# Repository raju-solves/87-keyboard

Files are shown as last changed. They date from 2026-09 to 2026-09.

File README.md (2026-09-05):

This project is a custom designed 87% ortholinear mechanical keyboard built as a PCB design and firmware learning experience It includes the PCB layout, CAD files, and firmware and lot of hardwork

I built this project to deepen my understanding of PCB design, keyboard matrix layouts, and CAD designing I wanted hands-on experience creating a mechanical keyboard from the scratch while also designing something practical and customized to my preference

602219003-d21ecfe0-0ab5-4783-b61b-950d579dc5c7
602219525-ffc2832b-7c2d-4a44-8d97-b2ba8af0c2ea
602219453-233b2a96-449a-4178-899f-5ae475d09add
602219381-5aa06178-03f3-4e05-a3e9-fc6733033b2a
602219333-37990960-18a9-4696-a77a-dc775576d171
602219100-f991f15e-3d26-4ee0-b814-e6c4a3add098
602219280-15e8cf9d-5e58-42b5-828d-d92529df9ab9
602219214-5e932b3e-5503-4928-bb83-d3fdaf1ea26e
602218932-bbe01e49-c888-48cc-bc79-f7ac42afa11e

| Name | Description | Quantity | Price (USD) | Link | Vendor |
|---|---|---|---|---|---|
| Gateron Mechanical Switches (G Pro 3.0 Yellow Pre-lubed) | Linear pre-lubed keyboard switches (~50g actuation, smooth) | 90 | 17.06 | https://www.thecosmicbyte.com/product/gateron-mechanical-switches-compatible-with-cosmic-byte-hot-swappable-keyboards-qty-1pc/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 | Cosmic Byte |
| Keycaps | Mechanical keyboard keycap set (standard layout) | 90 | 16.19 | https://amzn.in/d/05XbxYkm | Amazon |
| Diodes | General purpose diodes for keyboard matrix | 100 | 2.65 | https://amzn.in/d/0eVDrr6B | Amazon |
| PCB | Custom keyboard printed circuit board | 1 | 42.97 | N/A | JLCPCB |
| RP2040 | Microcontroller board (dual-core ARM Cortex-M0+) | 1 | 8.09 | https://amzn.in/d/00qoAonb | Amazon |
| Screws | Small M2/M2.5 screws for keyboard assembly | 1 pack | 1.53 | https://amzn.in/d/04wa89yN | Amazon |
| Stabilizers | PCB/plate mount stabilizers for larger keys | 1 set | 2.56 | https://www.aliexpress.us/item/3256806342416791.html | AliExpress |
| Soldering Iron | Basic soldering iron for assembling PCB components | 1 | 5.96 | https://amzn.in/d/032QO002 | Amazon |

**Total Cost: 99.01 USD**

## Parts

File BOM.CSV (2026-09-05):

# BOM
 | Name | Description | Quantity | Price (USD) | Link | Vendor
 | --- | --- | ---: | ---: | --- | ---
 | Gateron Mechanical Switches (G Pro 3.0 Yellow Pre-lubed) | Linear pre-lubed keyboard switches (~50g actuation, smooth) | 90 | $17.06 | [Product Link](https://www.thecosmicbyte.com/product/gateron-mechanical-switches-compatible-with-cosmic-byte-hot-swappable-keyboards-qty-1pc/ | Cosmic Byte
 | Keycaps | Mechanical keyboard keycap set (standard layout) | 90 | $16.19 | [Product Link](https://amzn.in/d/05XbxYkm) | Amazon
 | Diodes | General purpose diodes for keyboard matrix | 100 | $2.65 | [Product Link](https://amzn.in/d/0eVDrr6B) | Amazon
 | PCB | Custom keyboard printed circuit board | 1 | $42.97 | N/A | JLCPCB
 | RP2040 | Microcontroller board (dual-core ARM Cortex-M0+) | 1 | $8.09 | [Product Link](https://amzn.in/d/00qoAonb) | Amazon
 | Screws | Small M2/M2.5 screws for keyboard assembly | 1 pack | $1.53 | [Product Link](https://amzn.in/d/04wa89yN) | Amazon
 | Stabilizers | PCB/plate mount stabilizers for larger keys | 1 set | $2.56 | [Product Link](https://www.aliexpress.us/item/3256806342416791.html) | AliExpress
 | Soldering Iron | Basic soldering iron for assembling PCB components | 1 | $5.96 | [Product Link](https://amzn.in/d/032QO002) | Amazon
 | **Total** |  |  | **$97.01**

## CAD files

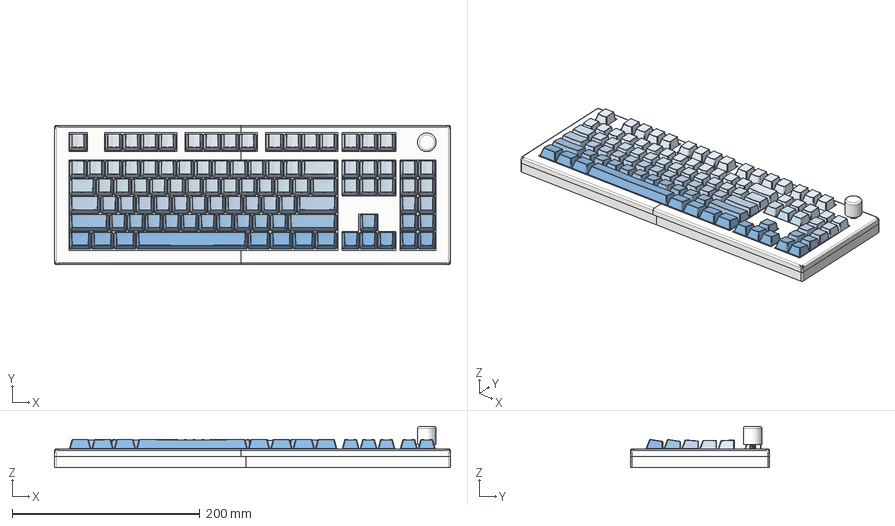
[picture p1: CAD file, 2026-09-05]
CAD/Assembly.step
421.8 x 148.4 x 43.8 mm

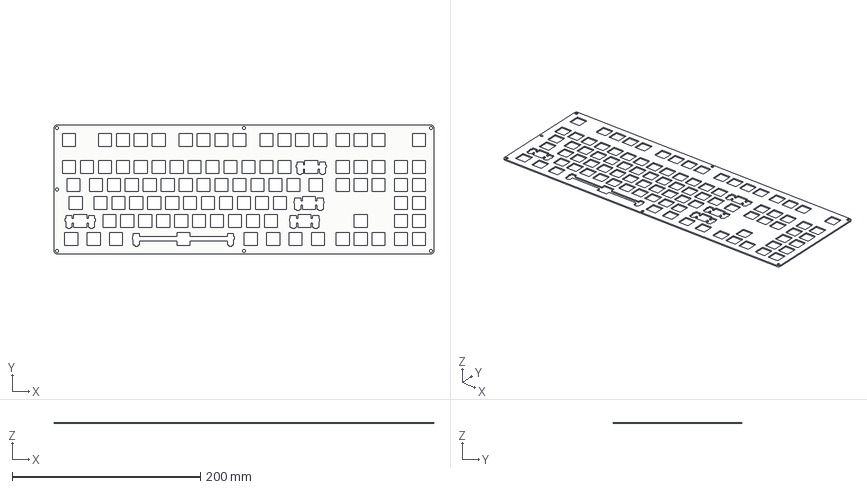
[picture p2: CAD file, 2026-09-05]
CAD/plate.step
403.3 x 136.6 x 1.50 mm

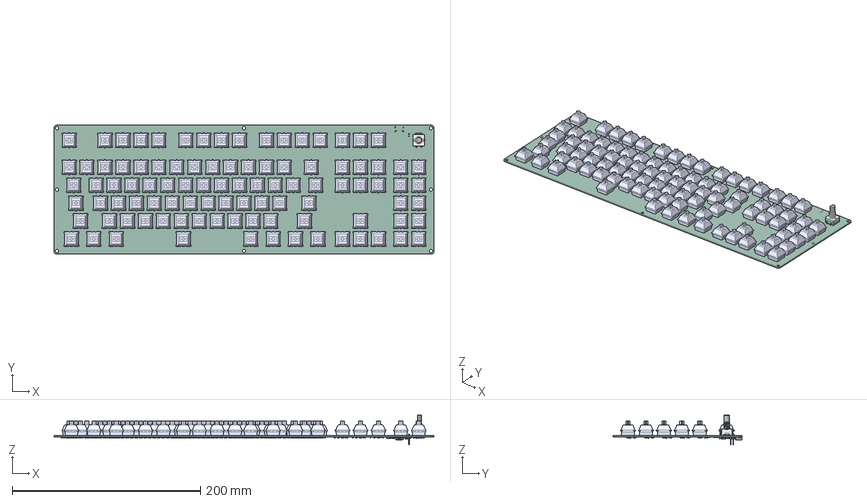
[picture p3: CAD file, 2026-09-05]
CAD/PCB.step
403.8 x 137.5 x 31.6 mm
Cherry_MX_Switch x 97
EC11_Vertical
D_SOD-323 x 98
PinHeader_1x02_P2.54mm_Vertical
C_0402_1005Metric x 15
R_0402_1005Metric x 6
R_0603_1608Metric x 2
C_1206_3216Metric x 2
Crystal_SMD_3225-4Pin_3.2x2.5mm
ConPins
PcbPins
Mold
Frame
QFN-56-1EP_7x7mm_P0.4mm_EP3.2x3.2mm
SOT-223
SOIC-8_3.9x4.9mm_P1.27mm
SOIC-8_5.3x5.3mm_P1.27mm
MacroBoard_PCB

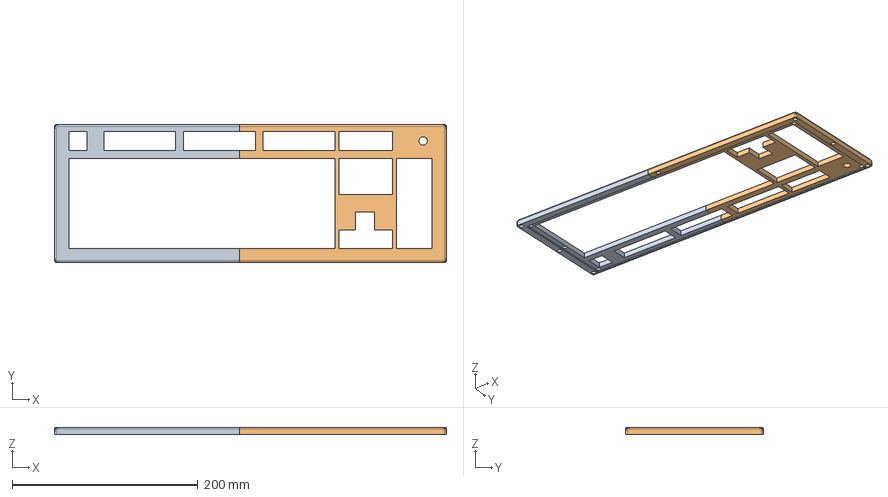
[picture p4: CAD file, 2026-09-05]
CAD/CaseTop.step
421.8 x 148.4 x 8.00 mm

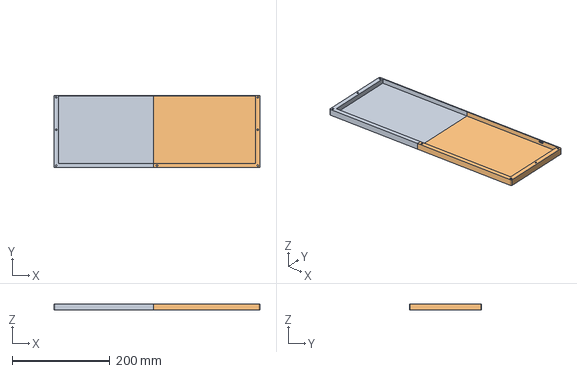
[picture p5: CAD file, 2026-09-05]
CAD/CaseBottom.step
421.8 x 148.4 x 12.0 mm

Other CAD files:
SOURCE FILE/MYKEEBO.FCStd

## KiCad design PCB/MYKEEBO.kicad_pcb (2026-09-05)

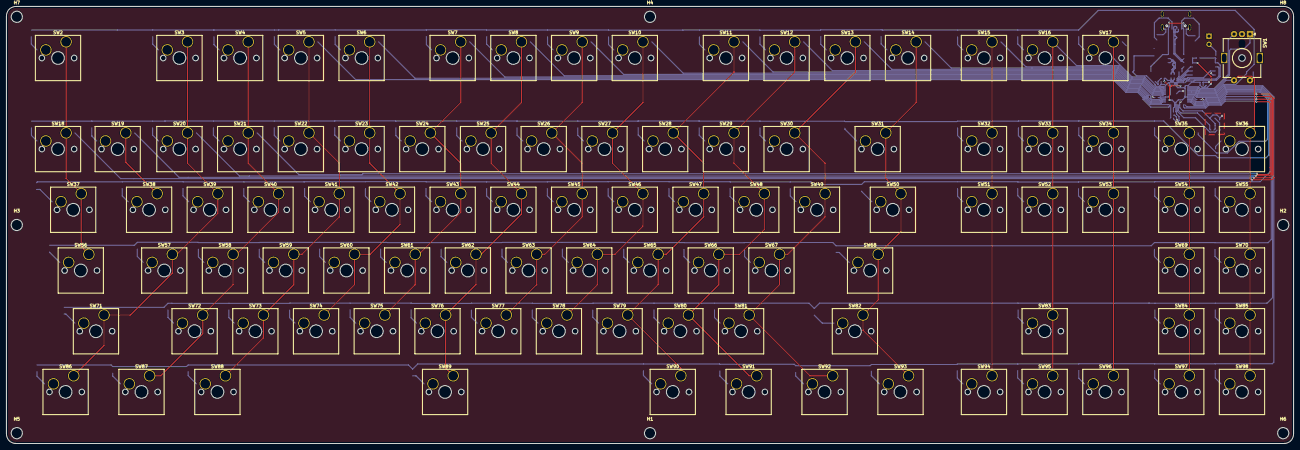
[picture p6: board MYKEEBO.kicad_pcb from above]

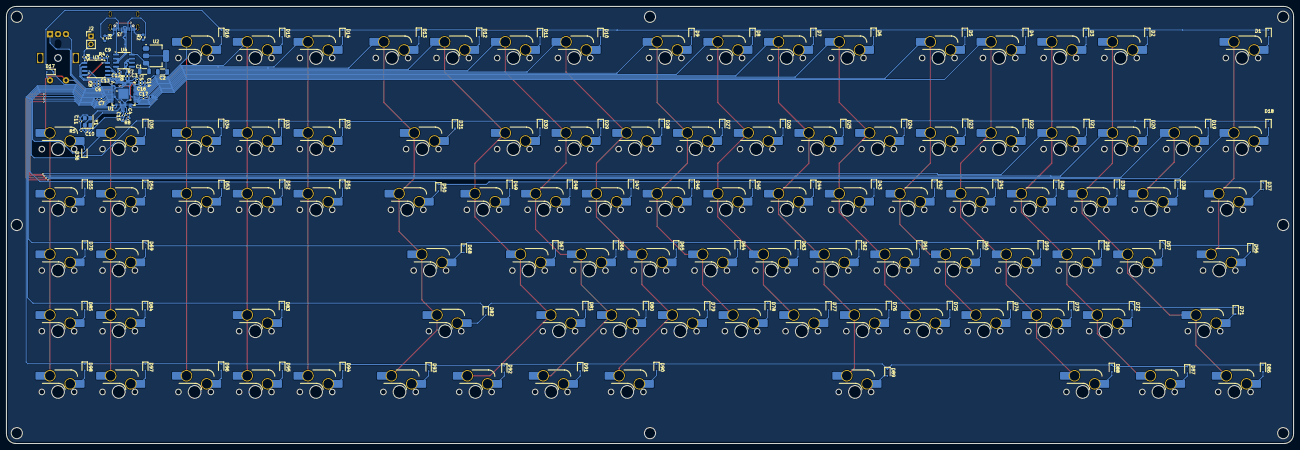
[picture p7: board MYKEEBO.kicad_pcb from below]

Board: 2 copper layers, 403.8 x 137.1 mm, 236 parts (130 on the bottom side), 148 nets.

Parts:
C1, C2: C10u; C_1206_3216Metric
C3, C5: C1u; C_0402_1005Metric
C4, C6, C7, C8, C9, C12, C13, C14, C15, C16, C17: C100n; C_0402_1005Metric
C10, C11: C15p; C_0402_1005Metric
D1: Esc; D_SOD-323
D2: F1; D_SOD-323
D3: F2; D_SOD-323
D4: F3; D_SOD-323
D5: F4; D_SOD-323
D6: F5; D_SOD-323
D7: F6; D_SOD-323
D8: F7; D_SOD-323
D9: F8; D_SOD-323
D10: F9; D_SOD-323
D11: F10; D_SOD-323
D12: F11; D_SOD-323
D13: F12; D_SOD-323
D14: PrtScrn; D_SOD-323
D15: Screen Lock; D_SOD-323
D16: Pause; D_SOD-323
D17: D; D_SOD-323
D18: KEY`; D_SOD-323
D19: KEY1; D_SOD-323
D20: KEY2; D_SOD-323
D21: KEY3; D_SOD-323
D22: KEY4; D_SOD-323
D23: KEY5; D_SOD-323
D24: KEY6; D_SOD-323
D25: KEY7; D_SOD-323
D26: KEY8; D_SOD-323
D27: KEY9; D_SOD-323
D28: KEY0; D_SOD-323
D29: KEY-; D_SOD-323
D30: KEY=; D_SOD-323
D31: BKSP; D_SOD-323
D32: Ins; D_SOD-323
D33: Home; D_SOD-323
D34: PgUP; D_SOD-323
D35: M1; D_SOD-323
D36: M2; D_SOD-323
D37: TAB; D_SOD-323
D38: KEYQ; D_SOD-323
D39: KEYW; D_SOD-323
D40: KEYE; D_SOD-323
D41: KEYR; D_SOD-323
D42: KEYT; D_SOD-323
D43: KEYY; D_SOD-323
D44: KEYU; D_SOD-323
D45: KEYI; D_SOD-323
D46: KEYO; D_SOD-323
D47: KEYP; D_SOD-323
D48: KEY[; D_SOD-323
D49: KEY]; D_SOD-323
D50: KEY\; D_SOD-323
D51: Del; D_SOD-323
D52: End; D_SOD-323
D53: PgDN; D_SOD-323
D54: M3; D_SOD-323
D55: M4; D_SOD-323
D56: CAPS; D_SOD-323
D57: KEYA; D_SOD-323
D58: KEYS; D_SOD-323
D59: KEYD; D_SOD-323
D60: KEYF; D_SOD-323
D61: KEYG; D_SOD-323
D62: KEYH; D_SOD-323
D63: KEYJ; D_SOD-323
D64: KEYK; D_SOD-323
D65: KEYL; D_SOD-323
D66: KEY;; D_SOD-323
D67: KEY"; D_SOD-323
D68: ENTER; D_SOD-323
D69: M5; D_SOD-323
D70: M6; D_SOD-323
D71: LSHIFT; D_SOD-323
D72: KEYZ; D_SOD-323
D73: KEYX; D_SOD-323
D74: KEYC; D_SOD-323
D75: KEYV; D_SOD-323
D76: KEYB; D_SOD-323
D77: KEYN; D_SOD-323
D78: KEYM; D_SOD-323
D79: KEY,; D_SOD-323
D80: KEY.; D_SOD-323
D81: KEY/; D_SOD-323
D82: RSHIFT; D_SOD-323
D83: Up Arrow; D_SOD-323
D84: M7; D_SOD-323
D85: M8; D_SOD-323
D86: LCTRL; D_SOD-323
D87: LWIN; D_SOD-323
D88: LALT; D_SOD-323
D89: SPACE; D_SOD-323
D90: RALT; D_SOD-323
D91: RWIN; D_SOD-323
D92: FN; D_SOD-323
D93: RCTRL; D_SOD-323
D94: Left Arrow; D_SOD-323
D95: Down Arrow; D_SOD-323
D96: Right Arrow; D_SOD-323
D97: M9; D_SOD-323
D98: M10; D_SOD-323
H1, H2, H3, H4, H5, H6, H7, H8: MountingHole; MountingHole_3.5mm
J2: Conn_01x02; PinHeader_1x02_P2.54mm_Vertical
J3: USBC; Korean Hroparts Elec - Type C 31 M 12 - 16P - USB 2.0
R1, R2: R5.1k; R_0603_1608Metric
R3: R1K; R_0402_1005Metric
R4: R10K; R_0402_1005Metric
R5: R1k; R_0402_1005Metric
R6, R7: R27.4; R_0402_1005Metric
R8: R10k; R_0402_1005Metric
SW1: RotaryEncoder_Switch; RotaryEncoder_Alps_EC11E-Switch_Vertical_H20mm_MountingHoles
SW2: Esc; SW_Hotswap_Kailh_MX_Plated_1.00u
SW3: F1; SW_Hotswap_Kailh_MX_Plated_1.00u
SW4: F2; SW_Hotswap_Kailh_MX_Plated_1.00u
SW5: F3; SW_Hotswap_Kailh_MX_Plated_1.00u
SW6: F4; SW_Hotswap_Kailh_MX_Plated_1.00u
SW7: F5; SW_Hotswap_Kailh_MX_Plated_1.00u
SW8: F6; SW_Hotswap_Kailh_MX_Plated_1.00u
SW9: F7; SW_Hotswap_Kailh_MX_Plated_1.00u
SW10: F8; SW_Hotswap_Kailh_MX_Plated_1.00u
SW11: F9; SW_Hotswap_Kailh_MX_Plated_1.00u
SW12: F10; SW_Hotswap_Kailh_MX_Plated_1.00u
SW13: F11; SW_Hotswap_Kailh_MX_Plated_1.00u
SW14: F12; SW_Hotswap_Kailh_MX_Plated_1.00u
SW15: PrtScrn; SW_Hotswap_Kailh_MX_Plated_1.00u
SW16: Screen Lock; SW_Hotswap_Kailh_MX_Plated_1.00u
SW17: Pause; SW_Hotswap_Kailh_MX_Plated_1.00u
SW18: KEY`; SW_Hotswap_Kailh_MX_Plated_1.00u
SW19: KEY1; SW_Hotswap_Kailh_MX_Plated_1.00u
SW20: KEY2; SW_Hotswap_Kailh_MX_Plated_1.00u
SW21: KEY3; SW_Hotswap_Kailh_MX_Plated_1.00u
SW22: KEY4; SW_Hotswap_Kailh_MX_Plated_1.00u
SW23: KEY5; SW_Hotswap_Kailh_MX_Plated_1.00u
SW24: KEY6; SW_Hotswap_Kailh_MX_Plated_1.00u
SW25: KEY7; SW_Hotswap_Kailh_MX_Plated_1.00u
SW26: KEY8; SW_Hotswap_Kailh_MX_Plated_1.00u
SW27: KEY9; SW_Hotswap_Kailh_MX_Plated_1.00u
SW28: KEY0; SW_Hotswap_Kailh_MX_Plated_1.00u
SW29: KEY-; SW_Hotswap_Kailh_MX_Plated_1.00u
SW30: KEY=; SW_Hotswap_Kailh_MX_Plated_1.00u
SW31: BKSP; SW_Hotswap_Kailh_MX_Plated_2.00u
SW32: Ins; SW_Hotswap_Kailh_MX_Plated_1.00u
SW33: Home; SW_Hotswap_Kailh_MX_Plated_1.00u
SW34: PgUP; SW_Hotswap_Kailh_MX_Plated_1.00u
SW35: M1; SW_Hotswap_Kailh_MX_Plated_1.00u
SW36: M2; SW_Hotswap_Kailh_MX_Plated_1.00u
SW37: TAB; SW_Hotswap_Kailh_MX_Plated_1.50u
SW38: KEYQ; SW_Hotswap_Kailh_MX_Plated_1.00u
SW39: KEYW; SW_Hotswap_Kailh_MX_Plated_1.00u
SW40: KEYE; SW_Hotswap_Kailh_MX_Plated_1.00u
SW41: KEYR; SW_Hotswap_Kailh_MX_Plated_1.00u
SW42: KEYT; SW_Hotswap_Kailh_MX_Plated_1.00u
SW43: KEYY; SW_Hotswap_Kailh_MX_Plated_1.00u
SW44: KEYU; SW_Hotswap_Kailh_MX_Plated_1.00u
SW45: KEYI; SW_Hotswap_Kailh_MX_Plated_1.00u
SW46: KEYO; SW_Hotswap_Kailh_MX_Plated_1.00u
SW47: KEYP; SW_Hotswap_Kailh_MX_Plated_1.00u
SW48: KEY[; SW_Hotswap_Kailh_MX_Plated_1.00u
SW49: KEY]; SW_Hotswap_Kailh_MX_Plated_1.00u
SW50: KEY\; SW_Hotswap_Kailh_MX_Plated_1.50u
SW51: Del; SW_Hotswap_Kailh_MX_Plated_1.00u
SW52: End; SW_Hotswap_Kailh_MX_Plated_1.00u
SW53: PgDN; SW_Hotswap_Kailh_MX_Plated_1.00u
SW54: M3; SW_Hotswap_Kailh_MX_Plated_1.00u
SW55: M4; SW_Hotswap_Kailh_MX_Plated_1.00u
SW56: CAPS; SW_Hotswap_Kailh_MX_Plated_1.75u
SW57: KEYA; SW_Hotswap_Kailh_MX_Plated_1.00u
SW58: KEYS; SW_Hotswap_Kailh_MX_Plated_1.00u
SW59: KEYD; SW_Hotswap_Kailh_MX_Plated_1.00u
SW60: KEYF; SW_Hotswap_Kailh_MX_Plated_1.00u
SW61: KEYG; SW_Hotswap_Kailh_MX_Plated_1.00u
SW62: KEYH; SW_Hotswap_Kailh_MX_Plated_1.00u
SW63: KEYJ; SW_Hotswap_Kailh_MX_Plated_1.00u
SW64: KEYK; SW_Hotswap_Kailh_MX_Plated_1.00u
SW65: KEYL; SW_Hotswap_Kailh_MX_Plated_1.00u
SW66: KEY;; SW_Hotswap_Kailh_MX_Plated_1.00u
SW67: KEY"; SW_Hotswap_Kailh_MX_Plated_1.00u
SW68: ENTER; SW_Hotswap_Kailh_MX_Plated_2.25u
SW69: M5; SW_Hotswap_Kailh_MX_Plated_1.00u
SW70: M6; SW_Hotswap_Kailh_MX_Plated_1.00u
SW71: LSHIFT; SW_Hotswap_Kailh_MX_Plated_2.25u
SW72: KEYZ; SW_Hotswap_Kailh_MX_Plated_1.00u
SW73: KEYX; SW_Hotswap_Kailh_MX_Plated_1.00u
SW74: KEYC; SW_Hotswap_Kailh_MX_Plated_1.00u
SW75: KEYV; SW_Hotswap_Kailh_MX_Plated_1.00u
SW76: KEYB; SW_Hotswap_Kailh_MX_Plated_1.00u
SW77: KEYN; SW_Hotswap_Kailh_MX_Plated_1.00u
SW78: KEYM; SW_Hotswap_Kailh_MX_Plated_1.00u
SW79: KEY,; SW_Hotswap_Kailh_MX_Plated_1.00u
SW80: KEY.; SW_Hotswap_Kailh_MX_Plated_1.00u
SW81: KEY/; SW_Hotswap_Kailh_MX_Plated_1.00u
SW82: RSHIFT; SW_Hotswap_Kailh_MX_Plated_2.75u
SW83: Up Arrow; SW_Hotswap_Kailh_MX_Plated_1.00u
SW84: M7; SW_Hotswap_Kailh_MX_Plated_1.00u
SW85: M8; SW_Hotswap_Kailh_MX_Plated_1.00u
SW86: LCTRL; SW_Hotswap_Kailh_MX_Plated_1.25u
SW87: LWIN; SW_Hotswap_Kailh_MX_Plated_1.25u
SW88: LALT; SW_Hotswap_Kailh_MX_Plated_1.25u
SW89: SPACE; SW_Hotswap_Kailh_MX_Plated_6.25u
SW90: RALT; SW_Hotswap_Kailh_MX_Plated_1.25u
SW91: RWIN; SW_Hotswap_Kailh_MX_Plated_1.25u
SW92: FN; SW_Hotswap_Kailh_MX_Plated_1.25u
SW93: RCTRL; SW_Hotswap_Kailh_MX_Plated_1.25u
SW94: Left Arrow; SW_Hotswap_Kailh_MX_Plated_1.00u
SW95: Down Arrow; SW_Hotswap_Kailh_MX_Plated_1.00u
SW96: Right Arrow; SW_Hotswap_Kailh_MX_Plated_1.00u
SW97: M9; SW_Hotswap_Kailh_MX_Plated_1.00u
SW98: M10; SW_Hotswap_Kailh_MX_Plated_1.00u
U1: RP2040; QFN-56-1EP_7x7mm_P0.4mm_EP3.2x3.2mm
U2: NCP1117-3.3_SOT223; SOT-223-3_TabPin2
U3: W25Q128JVS; SOIC-8_5.3x5.3mm_P1.27mm
U4: USB6B1; SOIC-8_3.9x4.9mm_P1.27mm
Y1: Crystal_GND24; Crystal_SMD_3225-4Pin_3.2x2.5mm

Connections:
+1V1: C3.2, C4.1, C12.1, U1.23 (DVDD), U1.45 (VREG_VOUT), U1.50 (DVDD)
+3.3V: C2.1, C5.1, C6.1, C7.1, C8.1, C9.1, C13.1, C14.1, C15.1, C16.1, C17.1, R4.2, R8.1, U1.1 (IOVDD), U1.10 (IOVDD), U1.22 (IOVDD), U1.33 (IOVDD), U1.42 (IOVDD), U1.43 (ADC_AVDD), U1.44 (VREG_IN), U1.48 (USB_VDD), U1.49 (IOVDD), U2.2 (VO), U3.8 (VCC)
+5V: C1.1, J3.A4/B9 (VBUS), J3.B4/A9 (VBUS), U2.3 (VI), U4.1 (VBUS), U4.8 (VBUS)
/D+: R6.1, U4.7 (I/O1)
/D-: R7.1, U4.6 (I/O2)
/PI_D+: R6.2, U1.47 (USB_DP)
/PI_D-: R7.2, U1.46 (USB_DM)
/QSPI_SCLK: U1.52 (QSPI_SCLK), U3.6 (CLK)
/QSPI_SD0: U1.53 (QSPI_SD0), U3.5 (DI/IO_{0})
/QSPI_SD1: U1.55 (QSPI_SD1), U3.2 (DO/IO_{1})
/QSPI_SD2: U1.54 (QSPI_SD2), U3.3 (~WP/IO_{2})
/QSPI_SD3: U1.51 (QSPI_SD3), U3.7 (~HOLD/~RESET/IO_{3})
/QSPI_SS: R3.2, R4.1, U1.56 (QSPI_SS), U3.1 (~CS)
/USB_D+: J3.A6 (DP1), J3.B6 (DP2), U4.2 (I/O1)
/USB_D-: J3.A7 (DN1), J3.B7 (DN2), U4.3 (I/O2)
/XIN: C10.2, U1.20 (XIN), Y1.1
/XOUT: R5.1, U1.21 (XOUT)
COL1: SW2.2, SW18.2, SW37.2, SW56.2, U1.13 (GPIO10)
COL2: SW19.2, SW38.2, U1.14 (GPIO11)
COL3: SW3.2, SW20.2, SW39.2, SW57.2, SW71.2, SW86.2, U1.15 (GPIO12)
COL4: SW4.2, SW21.2, SW40.2, SW58.2, SW72.2, SW87.2, U1.16 (GPIO13)
COL5: SW5.2, SW22.2, SW41.2, SW59.2, SW73.2, SW88.2, U1.27 (GPIO16)
COL6: SW6.2, SW23.2, SW42.2, SW60.2, SW74.2, U1.28 (GPIO17)
COL7: SW7.2, SW24.2, SW43.2, SW61.2, SW75.2, U1.29 (GPIO18)
COL8: SW8.2, SW25.2, SW44.2, SW62.2, SW76.2, SW89.2, U1.30 (GPIO19)
COL9: SW9.2, SW26.2, SW45.2, SW63.2, SW77.2, U1.31 (GPIO20)
COL10: SW10.2, SW27.2, SW46.2, SW64.2, SW78.2, U1.32 (GPIO21)
COL11: SW11.2, SW28.2, SW47.2, SW65.2, SW79.2, SW90.2, U1.35 (GPIO23)
COL12: SW12.2, SW29.2, SW48.2, SW66.2, SW80.2, SW91.2, U1.36 (GPIO24)
COL13: SW13.2, SW30.2, SW49.2, SW67.2, SW81.2, SW92.2, U1.37 (GPIO25)
COL14: SW14.2, SW31.2, SW50.2, SW68.2, SW82.2, SW93.2, U1.38 (GPIO26_ADC0)
COL15: SW15.2, SW32.2, SW51.2, SW94.2, U1.39 (GPIO27_ADC1)
COL16: SW16.2, SW33.2, SW52.2, SW83.2, SW95.2, U1.40 (GPIO28_ADC2)
COL17: SW17.2, SW34.2, SW53.2, SW96.2, U1.41 (GPIO29_ADC3)
COL18: SW35.2, SW54.2, SW69.2, SW84.2, SW97.2, U1.12 (GPIO9)
COL19: SW1.S1, SW36.2, SW55.2, SW70.2, SW85.2, SW98.2, U1.4 (GPIO2)
GND: C1.2, C2.2, C3.1, C4.2, C5.2, C6.2, C7.2, C8.2, C9.2, C10.1, C11.2, C12.2, C13.2, C14.2, C15.2, C16.2, C17.2, J2.1, J3.A1/B12 (GND), J3.B1/A12 (GND), J3.SH, R1.2, R2.2, SW1.C, U1.19 (TESTEN), U1.57 (GND), U2.1 (GND), U3.4 (GND), U4.4 (GND), U4.5 (GND), Y1.2, Y1.4
unnamed: C11.1, R5.2, Y1.3
unnamed: D1.2 (A), SW2.1
unnamed: D2.2 (A), SW3.1
unnamed: D3.2 (A), SW4.1
unnamed: D4.2 (A), SW5.1
unnamed: D5.2 (A), SW6.1
unnamed: D6.2 (A), SW7.1
unnamed: D7.2 (A), SW8.1
unnamed: D8.2 (A), SW9.1
unnamed: D9.2 (A), SW10.1
unnamed: D10.2 (A), SW11.1
unnamed: D11.2 (A), SW12.1
unnamed: D12.2 (A), SW13.1
unnamed: D13.2 (A), SW14.1
unnamed: D14.2 (A), SW15.1
unnamed: D15.2 (A), SW16.1
unnamed: D16.2 (A), SW17.1
unnamed: D17.2 (A), SW1.S2
unnamed: D18.2 (A), SW18.1
unnamed: D19.2 (A), SW19.1
unnamed: D20.2 (A), SW20.1
unnamed: D21.2 (A), SW21.1
unnamed: D22.2 (A), SW22.1
unnamed: D23.2 (A), SW23.1
unnamed: D24.2 (A), SW24.1
unnamed: D25.2 (A), SW25.1
unnamed: D26.2 (A), SW26.1
unnamed: D27.2 (A), SW27.1
unnamed: D28.2 (A), SW28.1
unnamed: D29.2 (A), SW29.1
unnamed: D30.2 (A), SW30.1
unnamed: D31.2 (A), SW31.1
unnamed: D32.2 (A), SW32.1
unnamed: D33.2 (A), SW33.1
unnamed: D34.2 (A), SW34.1
unnamed: D35.2 (A), SW35.1
unnamed: D36.2 (A), SW36.1
unnamed: D37.2 (A), SW37.1
unnamed: D38.2 (A), SW38.1
unnamed: D39.2 (A), SW39.1
unnamed: D40.2 (A), SW40.1
unnamed: D41.2 (A), SW41.1
unnamed: D42.2 (A), SW42.1
unnamed: D43.2 (A), SW43.1
unnamed: D44.2 (A), SW44.1
unnamed: D45.2 (A), SW45.1
unnamed: D46.2 (A), SW46.1
unnamed: D47.2 (A), SW47.1
unnamed: D48.2 (A), SW48.1
unnamed: D49.2 (A), SW49.1
unnamed: D50.2 (A), SW50.1
unnamed: D51.2 (A), SW51.1
unnamed: D52.2 (A), SW52.1
unnamed: D53.2 (A), SW53.1
unnamed: D54.2 (A), SW54.1
unnamed: D55.2 (A), SW55.1
unnamed: D56.2 (A), SW56.1
unnamed: D57.2 (A), SW57.1
unnamed: D58.2 (A), SW58.1
unnamed: D59.2 (A), SW59.1
unnamed: D60.2 (A), SW60.1
unnamed: D61.2 (A), SW61.1
unnamed: D62.2 (A), SW62.1
unnamed: D63.2 (A), SW63.1
unnamed: D64.2 (A), SW64.1
unnamed: D65.2 (A), SW65.1
unnamed: D66.2 (A), SW66.1
unnamed: D67.2 (A), SW67.1
unnamed: D68.2 (A), SW68.1
unnamed: D69.2 (A), SW69.1
unnamed: D70.2 (A), SW70.1
unnamed: D71.2 (A), SW71.1
unnamed: D72.2 (A), SW72.1
unnamed: D73.2 (A), SW73.1
unnamed: D74.2 (A), SW74.1
unnamed: D75.2 (A), SW75.1
unnamed: D76.2 (A), SW76.1
unnamed: D77.2 (A), SW77.1
unnamed: D78.2 (A), SW78.1
unnamed: D79.2 (A), SW79.1
unnamed: D80.2 (A), SW80.1
unnamed: D81.2 (A), SW81.1
unnamed: D82.2 (A), SW82.1
unnamed: D83.2 (A), SW83.1
unnamed: D84.2 (A), SW84.1
unnamed: D85.2 (A), SW85.1
unnamed: D86.2 (A), SW86.1
unnamed: D87.2 (A), SW87.1
unnamed: D88.2 (A), SW88.1
unnamed: D89.2 (A), SW89.1
unnamed: D90.2 (A), SW90.1
unnamed: D91.2 (A), SW91.1
unnamed: D92.2 (A), SW92.1
unnamed: D93.2 (A), SW93.1
unnamed: D94.2 (A), SW94.1
unnamed: D95.2 (A), SW95.1
unnamed: D96.2 (A), SW96.1
unnamed: D97.2 (A), SW97.1
unnamed: D98.2 (A), SW98.1
unnamed: J2.2, R3.1
unnamed: J3.A5 (CC1), R2.1
unnamed: J3.B5 (CC2), R1.1
unnamed: R8.2, U1.26 (RUN)
ROTA: SW1.A, U1.3 (GPIO1)
ROTB: SW1.B, U1.2 (GPIO0)
ROW1: D1.1 (K), D2.1 (K), D3.1 (K), D4.1 (K), D5.1 (K), D6.1 (K), D7.1 (K), D8.1 (K), D9.1 (K), D10.1 (K), D11.1 (K), D12.1 (K), D13.1 (K), D14.1 (K), D15.1 (K), D16.1 (K), D17.1 (K), U1.5 (GPIO3)
ROW2: D18.1 (K), D19.1 (K), D20.1 (K), D21.1 (K), D22.1 (K), D23.1 (K), D24.1 (K), D25.1 (K), D26.1 (K), D27.1 (K), D28.1 (K), D29.1 (K), D30.1 (K), D31.1 (K), D32.1 (K), D33.1 (K), D34.1 (K), D35.1 (K), D36.1 (K), U1.11 (GPIO8)
ROW3: D37.1 (K), D38.1 (K), D39.1 (K), D40.1 (K), D41.1 (K), D42.1 (K), D43.1 (K), D44.1 (K), D45.1 (K), D46.1 (K), D47.1 (K), D48.1 (K), D49.1 (K), D50.1 (K), D51.1 (K), D52.1 (K), D53.1 (K), D54.1 (K), D55.1 (K), U1.9 (GPIO7)
ROW4: D56.1 (K), D57.1 (K), D58.1 (K), D59.1 (K), D60.1 (K), D61.1 (K), D62.1 (K), D63.1 (K), D64.1 (K), D65.1 (K), D66.1 (K), D67.1 (K), D68.1 (K), D69.1 (K), D70.1 (K), U1.8 (GPIO6)
ROW5: D71.1 (K), D72.1 (K), D73.1 (K), D74.1 (K), D75.1 (K), D76.1 (K), D77.1 (K), D78.1 (K), D79.1 (K), D80.1 (K), D81.1 (K), D82.1 (K), D83.1 (K), D84.1 (K), D85.1 (K), U1.7 (GPIO5)
ROW6: D86.1 (K), D87.1 (K), D88.1 (K), D89.1 (K), D90.1 (K), D91.1 (K), D92.1 (K), D93.1 (K), D94.1 (K), D95.1 (K), D96.1 (K), D97.1 (K), D98.1 (K), U1.6 (GPIO4)

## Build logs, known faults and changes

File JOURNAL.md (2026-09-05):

# Keyboard Build Journal

## Project Overview

This journal covers the complete process of designing and preparing my custom keyboard project, from the first planning stage to the final BOM, firmware planning, DRC checks, CAD, PCB work, and final submission.

| Stage | Time |
|---|---:|
| Planning and Research | 1 hour |
| Schematic and Matrix Wiring | 3 hours |
| Starting PCB | 3 hours |
| Final PCB and 3D View | 3 hours |
| Basic CAD Work | 3 hours |
| Final CAD and Assembly | 3 hours |
| BOM, Firmware, DRC and Final Submit | 3 hours |
| **Total** | **19 hours** |

---

## 1. Planning and Research ( 1 sep )

**Time spent: 1 hour**  
**Running total: 1 hour**

I started by planning the overall design and figuring out what components I would need for the keyboard.

Even after building a macropad before, I underestimated how complex a full TKL keyboard would be. I worked out the layout with 87 keys, macros, and an encoder, and calculated the matrix and GPIO requirements.

Most of this stage was spent reading documentation and comparing parts, which took a lot longer than expected. I also began sourcing components like switches, diodes, USB-C parts, and the RP2040.

Along the way, I learned more about things like ESD protection, capacitors, and JLCPCB part categories.

This phase was slow, but it was important because it gave me a strong foundation before starting the schematic and PCB.

1774334749925-idjm1u
1774334100199-u5o96o

---

## 2. Schematic and Matrix Wiring ( 1 sep )

**Time spent: 3 hours**  
**Running total: 4 hours**

After finishing the planning and sourcing, I moved on to creating the schematic.

This was where everything started coming together. I connected all the switches using diodes and arranged them into a proper keyboard matrix.

At first, managing all the rows and columns was a bit confusing, so I had to recheck my connections multiple times to avoid mistakes.

I also added the RP2040, USB-C connection, and supporting components such as capacitors and resistors.

The wiring was fairly straightforward because this was the second time I had gone through the RP2040 hardware documentation. The first time was while researching and sourcing parts, so I was already familiar with most of it.

1774335068468-b4xk0i
1774335049380-znrj0v

---

## 3. Starting PCB ( 2 sep )

**Time spent: 3 hours**  
**Running total: 7 hours**

After finishing the schematic, I finally moved on to the PCB.

This was honestly much harder than I expected.

Placing all the switches took a while because I had to make sure everything lined up properly with the intended keyboard layout.

Once I started routing, things became even more confusing. There were many connections, and I kept reaching situations where one trace blocked another, so I had to undo parts of the routing and try again.

At one point I thought I had planned the routing properly, but it still did not work out.

After a lot of trial and error, I slowly managed to get most of the traces connected in a cleaner way.

Seeing the PCB finally start to come together after all the routing struggle felt really satisfying.

1774339837583-d92abk
1774339837583-d92abk

---

## 4. Final PCB and 3D View ( 3 sep )

**Time spent: 3 hours**  
**Running total: 10 hours**

I continued routing the PCB and connected most of the rows and columns.

I also rearranged the crystal so that I could create a better ground plane around it.

Most of this stage was fairly straightforward, but routing still became difficult in some areas. I had to keep rearranging parts so the traces could fit properly without blocking other connections.

Sometimes I had to stop and think about how to connect two tracks without boxing myself in for the remaining rows and columns.

I also noticed that some power symbols were using `3V3` while others were using `3.3`, which caused the nets to be slightly incorrect. I fixed those inconsistencies and continued wiring the board.

Most of this stage was also spent checking everything again and making sure I had not missed anything obvious.

I cleaned up parts of the PCB as well so the board did not look too chaotic.

Seeing a complete PCB after all the routing work felt really satisfying.

1774340357177-igap18
1774340367724-7z4org
1774340683749-1g0x80

---

## 5. Basic CAD Work ( 3 sep )

**Time spent: 3 hours**  
**Running total: 13 hours**

After finishing the PCB, I started working on the plate and some basic CAD for the keyboard structure.

I am still pretty new to CAD, so making the case took longer than expected.

This part felt very different from the PCB work.

I had to make sure all the switch cutouts lined up correctly with the PCB, which required several adjustments.

I also experimented with how the top and bottom parts of the keyboard would fit together, even though I did not go too deep into making a complete enclosure.

Some measurements did not match at first, so I had to tweak the spacing and alignment.

It was not perfect, but this stage gave me a much better idea of how the keyboard would physically come together.

1774341623539-49usxy
1774341606377-c016h3
1774341495177-vj7xi5
1774341467706-7451nc

---

## 6. Final CAD and Assembly ( 4 sep)

**Time spent: 3 hours**  
**Running total: 16 hours**

After working on the plate and basic CAD, the next step was figuring out how everything would actually come together in the final build.

I started planning the assembly process, including how the switches, plate, PCB, stabilizers, and keycaps would fit together.

At the same time, I also looked into firmware and how the keymap would be implemented.

I added all the keycaps to the model, but this took much longer than it should have because I was initially moving and copying them one by one.

Later, I learned that I could use rectangular patterns, which made the process much faster.

Once the keycaps were finally in place, the whole keyboard started to look like a real finished product.

Seeing how the switches and stabilizers fit together in the model also helped me check for possible mistakes.

One of the next things I needed to verify was that there was enough space between the plate and PCB so nothing would get jammed or bent during assembly.

1774355283896-w0w1fb
1774355250516-618swm
1774355236590-174on1

---

## 7. BOM, Firmware, DRC and Final Submit ( 5 sep)

**Time spent: 3 hours**  
**Running total: 19 hours**

At this point, I was finally ready to wrap up and submit the project.

I had completed the CAD, assembly planning, PCB routing, and the rest of the main design work.

I reviewed the full project again and focused on making sure everything felt complete.

I finalized the BOM with all the components I had researched, including the RP2040, switches, diodes, stabilizers, and other supporting parts.

I also looked into the firmware side of the keyboard and planned how the keymap would be implemented based on my layout.

Finally, I ran the DRC check on the PCB.

The result showed **0 errors**, which was a great way to finish the design stage.

After all the planning, routing, CAD work, checking, and revisions, the project was finally ready for submission.

1774355875989-si8xcu
1774355792093-dncbrq

---

# Final Time

**Total project time: 19 hours**

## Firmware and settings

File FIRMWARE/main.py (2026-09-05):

import board

from kmk.kmk_keyboard import KMKKeyboard
from kmk.keys import KC
from kmk.scanners import DiodeOrientation
from kmk.modules.encoder import EncoderHandler
from kmk.extensions.media_keys import MediaKeys
from kmk.modules.layers import Layers




encoder_handler = EncoderHandler()

keyboard = KMKKeyboard()

keyboard.modules.append(encoder_handler)
keyboard.modules.append(MediaKeys())
keyboard.modules.append(Layers())

encoder_handler.pins = [
    (board.GP0,board.GP1,None)
]
encoder_handler.map = [
    [(KC.VOLD,KC.VOLU,None)]
]


layer = KC.MO(1)

keyboard.col_pins = (board.GP16,board.GP17,board.GP18,board.GP19,board.GP20,board.GP21,board.GP22,board.GP26,board.GP27,board.GP28,board.GP11,board.GP12,board.GP13,board.GP14,board.GP15,board.GP10,board.GP9,board.GP8)
keyboard.row_pins = (board.GP2,board.GP3,board.GP4,board.GP5,board.GP7,board.GP6)
keyboard.diode_orientation = DiodeOrientation.COL2ROW

keyboard.keymap = [
    [KC.ESC,KC.N6,None,None,None,None,None,None,None,None,None,None,None,None,KC.PSCR,KC.SLCK,KC.PAUSE,KC.MUTE,
     KC.GRAVE,KC.N1,KC.N2,KC.N3,KC.N4,KC.N5,KC.N7,KC.N8,KC.N9,KC.N0,KC.MINS,KC.EQUAL,KC.BSPACE,KC.INS,KC.HOME,KC.PGUP,KC.F13,KC.F14,
     KC.TAB,KC.Q,KC.W,KC.E,KC.R,KC.T,KC.U,KC.I,KC.O,KC.P,KC.LBRACKET,KC.RBRACKET,KC.BSLASH,KC.DEL,KC.END,KC.PGDN,KC.F23,KC.F16,
     KC.CAPS,KC.A,KC.S,KC.D,KC.F,KC.G,KC.H,KC.J,KC.K,KC.L,KC.SCOLON,KC.QUOTE,KC.ENTER,None,None,None,KC.F17,KC.F18,
     KC.LSHIFT,KC.Z,KC.X,KC.C,KC.V,KC.B,KC.N,KC.M,KC.COMMA,KC.DOT,KC.SLASH,None,KC.RSHIFT,None,KC.UP,None,KC.F19,KC.F20,
     KC.LCTRL,KC.LWIN,KC.LALT,None,None,KC.SPACE,KC.Y,None,None,KC.RALT,layer,KC.RWIN,KC.RCTRL,KC.LEFT,KC.DOWN,KC.RIGHT,KC.F21,KC.F22],
    

    [KC.ESC,KC.N6,KC.F1,KC.F2,KC.F3,KC.F4,KC.F5,KC.F6,KC.F7,KC.F8,KC.F9,KC.F10,KC.F11,KC.F12,KC.PSCR,KC.SLCK,KC.PAUSE,KC.MUTE,
     KC.GRAVE,KC.N1,KC.N2,KC.N3,KC.N4,KC.N5,KC.N7,KC.N8,KC.N9,KC.N0,KC.MINS,KC.EQUAL,KC.BSPACE,KC.INS,KC.HOME,KC.PGUP,KC.F13,KC.F14,
     KC.TAB,KC.Q,KC.W,KC.E,KC.R,KC.T,KC.U,KC.I,KC.O,KC.P,KC.LBRACKET,KC.RBRACKET,KC.BSLASH,KC.DEL,KC.END,KC.PGDN,KC.F23,KC.F16,
     KC.CAPS,KC.A,KC.S,KC.D,KC.F,KC.G,KC.H,KC.J,KC.K,KC.L,KC.SCOLON,KC.QUOTE,KC.ENTER,None,None,None,KC.F17,KC.F18,
     KC.LSHIFT,KC.Z,KC.X,KC.C,KC.V,KC.B,KC.N,KC.M,KC.COMMA,KC.DOT,KC.SLASH,None,KC.RSHIFT,None,KC.UP,None,KC.F19,KC.F20,
     KC.LCTRL,KC.LWIN,KC.LALT,None,None,KC.SPACE,KC.Y,None,None,KC.RALT,layer,KC.RWIN,KC.RCTRL,KC.LEFT,KC.DOWN,KC.RIGHT,KC.F21,KC.F22]
]

if __name__ == "__main__":
    keyboard.go()
